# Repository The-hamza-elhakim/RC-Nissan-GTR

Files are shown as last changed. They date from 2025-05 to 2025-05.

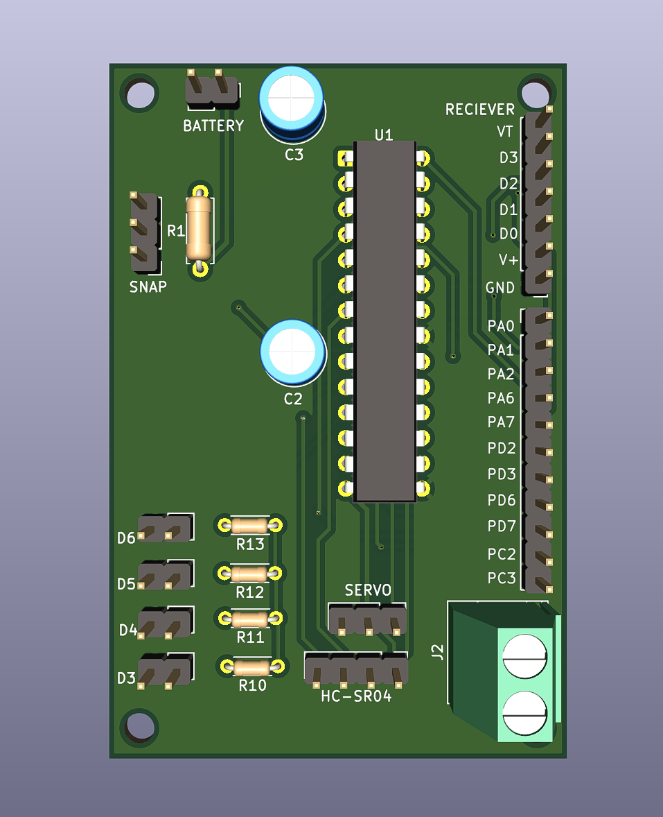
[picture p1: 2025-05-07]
Documentation/PCB schematics (KICAD)/Main PCB.png

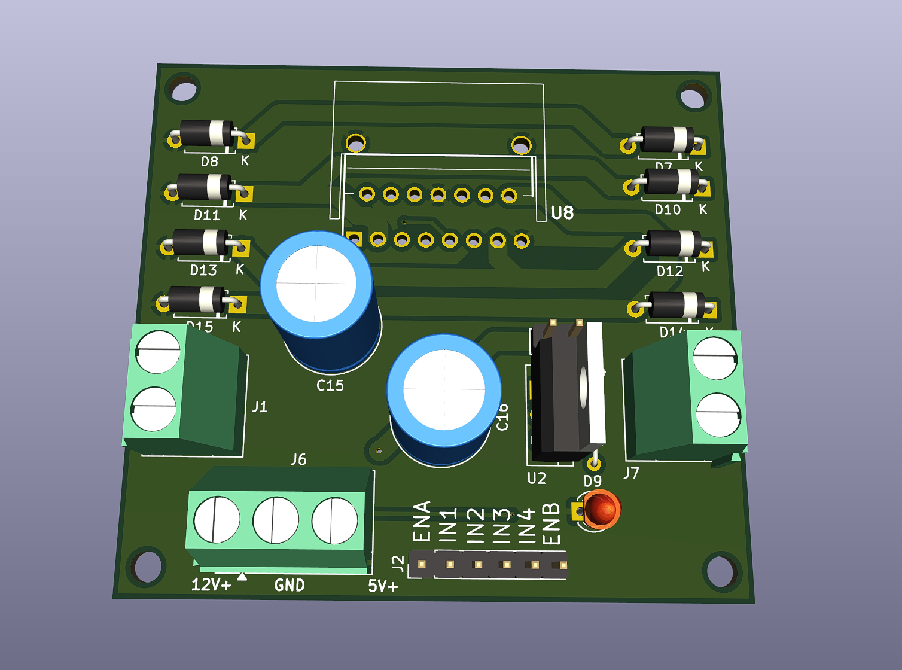
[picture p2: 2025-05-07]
Documentation/PCB schematics (KICAD)/L298N PCB.png

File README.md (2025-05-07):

# ENEL 300 RC Car – Embedded Systems Final Project

# RC-Nissan-GTR
RC Car modeled after the Iconic Nissan GTR r35. Designed from scratch using AVR128DB28 MCU, ultrasonic sensors, joystick control, I2C LCD, and L298N motor driver. Built in MPLAB X, with custom PCBs, bare-metal C firmware, and real-time sensor feedback.

## Overview
This project is a fully functional RC car built from scratch using embedded C on the AVR128DB28 microcontroller. It includes:

- motor control via custom built L298N motor driver PCB
- Ultrasonic sensor for obstacle detection
- 4 digit display for distance feedback
- Remote controller using joystick module (KY-023) and Wireless 433Mhz RF Transmitter/Receiver Modules
- Custom PCBs and real-time sensor integration

## Features
- Real-time distance sensing (HC-SR04)
- Metal detection with buzzer output
- Headlight control (GPIO driven)
- Directional motor control with PWM
- I2C LCD for debug/status

## Technologies
- AVR128DB28 microcontroller
- Bare-metal C (no Arduino)
- MPLAB X IDE
- I2C, PWM, ADC, GPIO
- Custom PCB Design (KiCAD)

## Documentation
See [`Documentation/`](Documentation/) folder for project reports and architecture

Read the full project report here:  
[ENEL 300 RC Car Final Report (Google Docs)](https://docs.google.com/document/d/1p-epSyup4PSlBaB8h3Y5LkGUN4icb1V6V-HfzxVr1pI/edit?tab=t.0)

## Author
Hamza Elhakim – Electrical and Computer Engineering Student

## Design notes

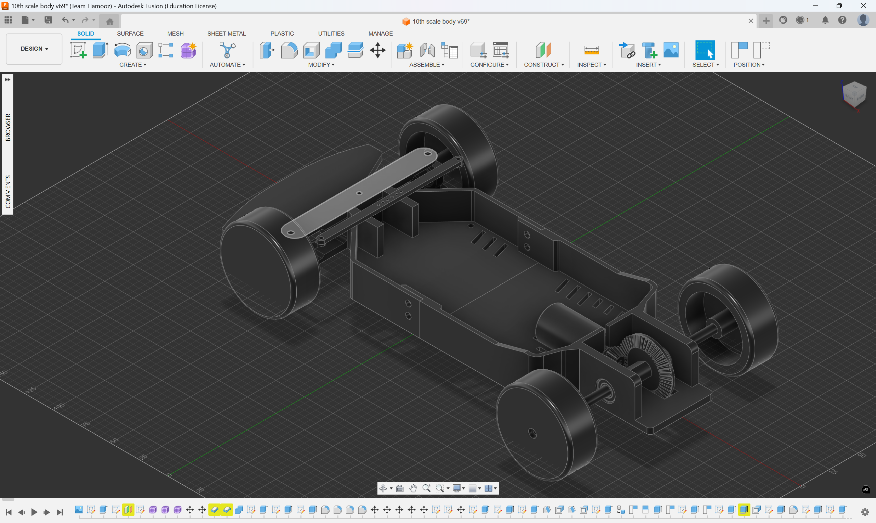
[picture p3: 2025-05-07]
Documentation/3D print designs (Fusion 360)/chassis.png

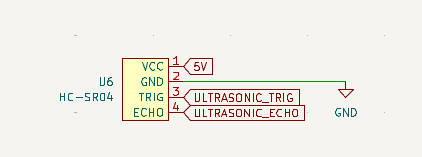
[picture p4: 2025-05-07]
Documentation/PCB schematics (KICAD)/Ultrasonic sensor.png

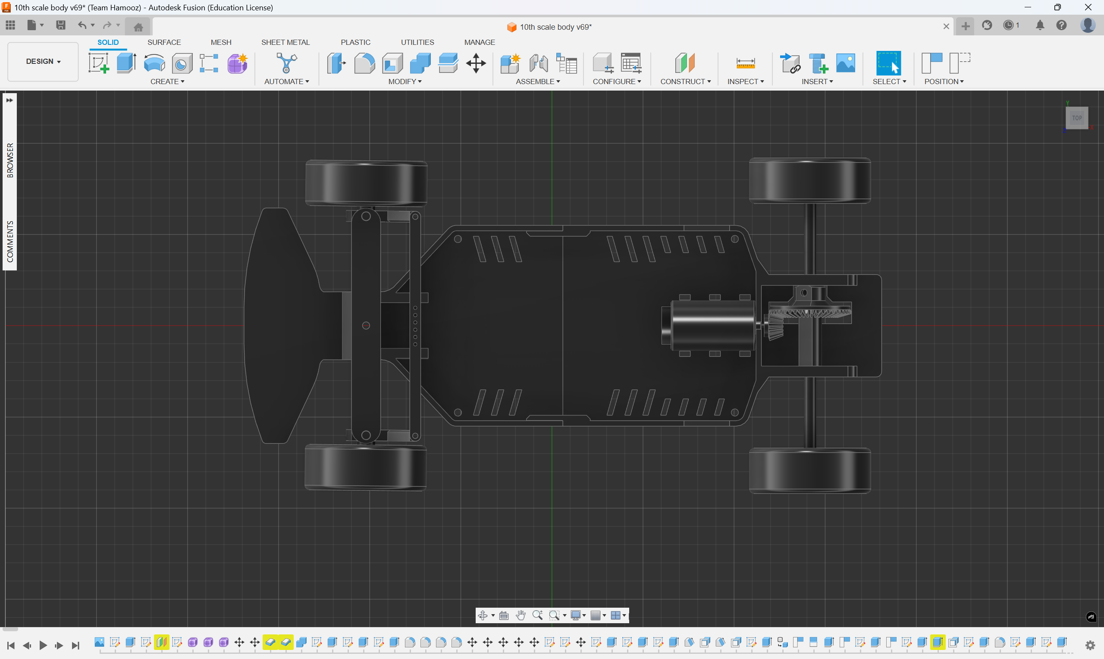
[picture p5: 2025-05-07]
Documentation/3D print designs (Fusion 360)/top view (chassis).png

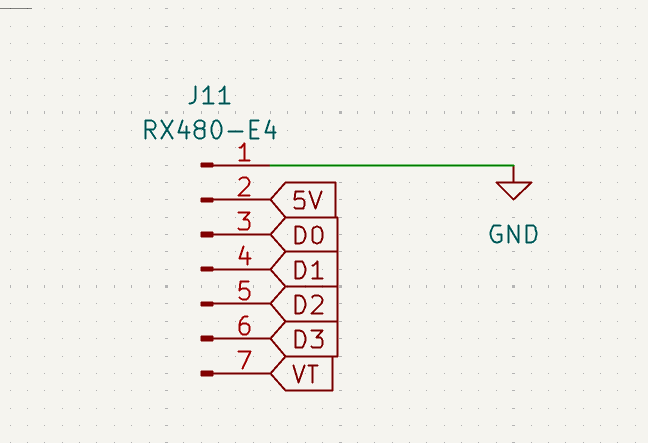
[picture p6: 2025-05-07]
Documentation/PCB schematics (KICAD)/Reciever.png

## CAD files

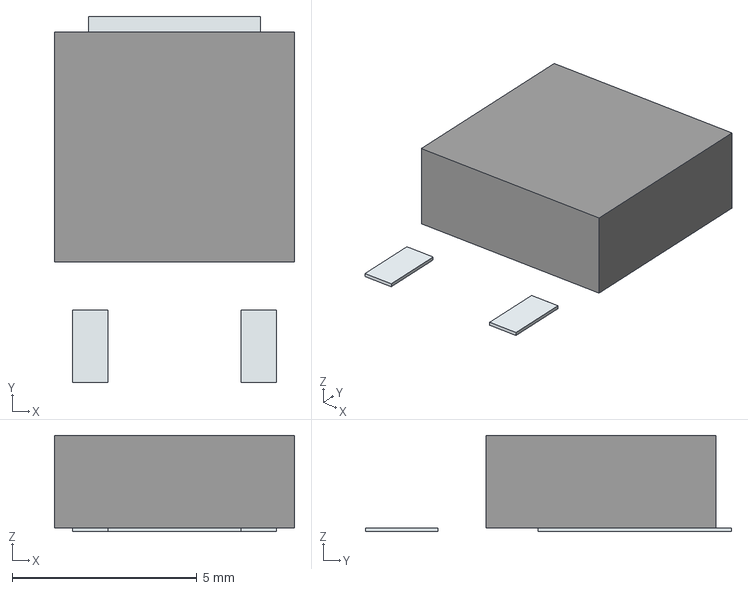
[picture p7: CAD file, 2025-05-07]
Hardware/Main/LIB_IPD90P03P4L04ATMA2/IPD90P03P4L04ATMA2/3D/IPD90P03P4L04ATMA2.stp
6.50 x 9.90 x 2.60 mm
Pins

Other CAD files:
Hardware/Main/LIB_IPD90P03P4L04ATMA2/IPD90P03P4L04ATMA2/Allegro/ipd90p03p4l04atma2.psm
Hardware/Main/LIB_IPD90P03P4L04ATMA2/IPD90P03P4L04ATMA2/DEHDL/ipd90p03p4l04atma2/chips/chips.prt

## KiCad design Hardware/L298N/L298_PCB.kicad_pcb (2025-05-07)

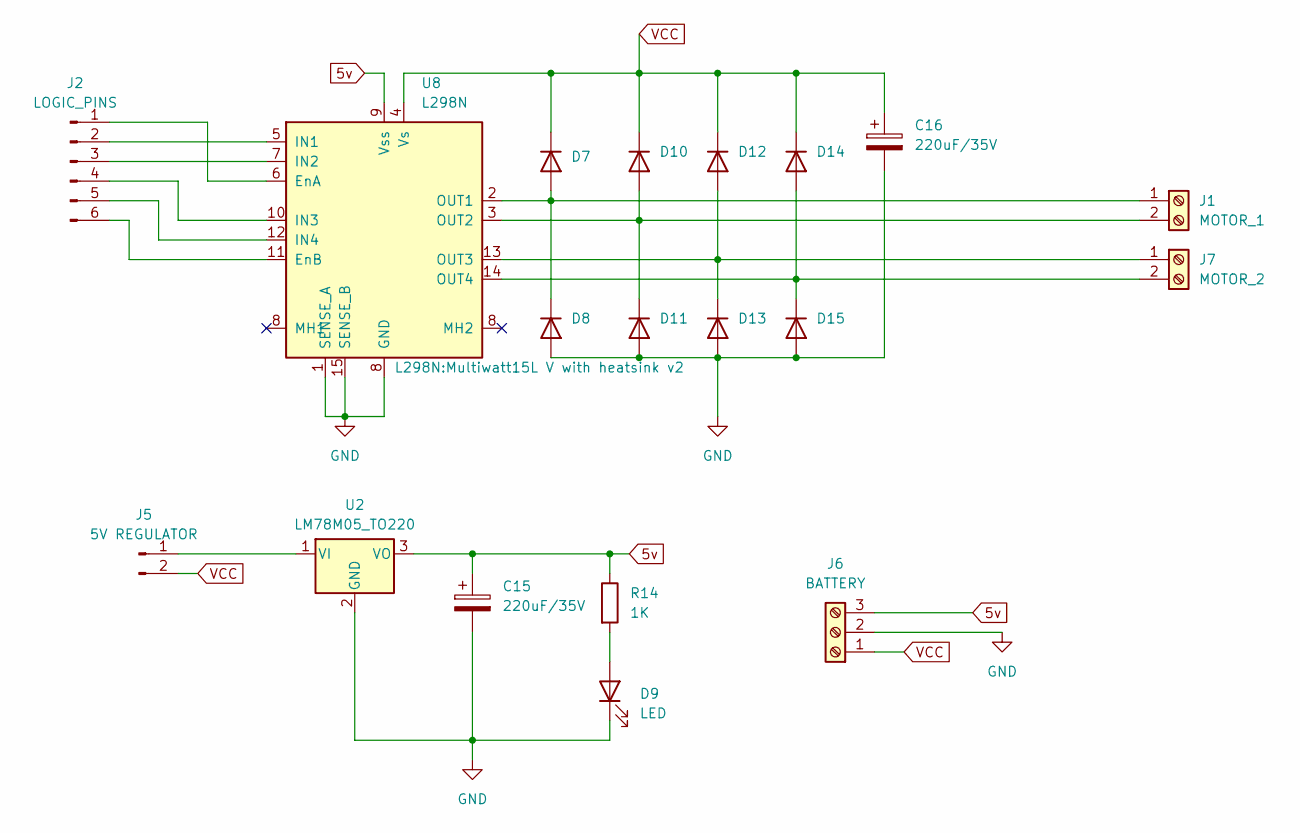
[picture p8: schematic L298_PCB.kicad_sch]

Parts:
C15, C16: 220uF/35V; C_Radial_D10.0mm_H16.0mm_P5.00mm
D7: D_A-405_P7.62mm_Horizontal
D8, D10, D11, D12, D13, D14, D15: .; D_A-405_P7.62mm_Horizontal
D9: LED; LED_D3.0mm
J1: MOTOR_1; TerminalBlock_Phoenix_MKDS-1,5-2-5.08_1x02_P5.08mm_Horizont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
J2: LOGIC_PINS; PinHeader_1x06_P2.54mm_Vertical
J5: 5V REGULATOR; PinHeader_1x02_P2.54mm_Vertical
J6: BATTERY; TerminalBlock_Phoenix_MKDS-1,5-3_1x03_P5.00mm_Horizontal
J7: MOTOR_2; TerminalBlock_Phoenix_MKDS-1,5-2-5.08_1x02_P5.08mm_Horizont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
R14: 1K; R_Axial_DIN0204_L3.6mm_D1.6mm_P7.62mm_Horizontal
U2: LM78M05_TO220; TO-220-3_Vertical
U8: L298N; Multiwatt15L V with heatsink v2

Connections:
5v: C15.1, J6.3, R14.1, U2.3 (VO), U8.9 (Vss)
GND: C15.2, C16.2, D8.2 (A), D9.1 (K), D11.2 (A), D13.2 (A), D15.2 (A), J6.2, U2.2 (GND), U8.1 (SENSE_A), U8.8 (GND), U8.15 (SENSE_B)
unnamed: D7.2 (A), D8.1 (K), J1.1, U8.2 (OUT1)
unnamed: D9.2 (A), R14.2
unnamed: D10.2 (A), D11.1 (K), J1.2, U8.3 (OUT2)
unnamed: D12.2 (A), D13.1 (K), J7.1, U8.13 (OUT3)
unnamed: D14.2 (A), D15.1 (K), J7.2, U8.14 (OUT4)
unnamed: J2.1, U8.6 (EnA)
unnamed: J2.2, U8.5 (IN1)
unnamed: J2.3, U8.7 (IN2)
unnamed: J2.4, U8.10 (IN3)
unnamed: J2.5, U8.12 (IN4)
unnamed: J2.6, U8.11 (EnB)
unnamed: J5.1, U2.1 (VI)
VCC: C16.1, D7.1 (K), D10.1 (K), D12.1 (K), D14.1 (K), J5.2, J6.1, U8.4 (Vs)

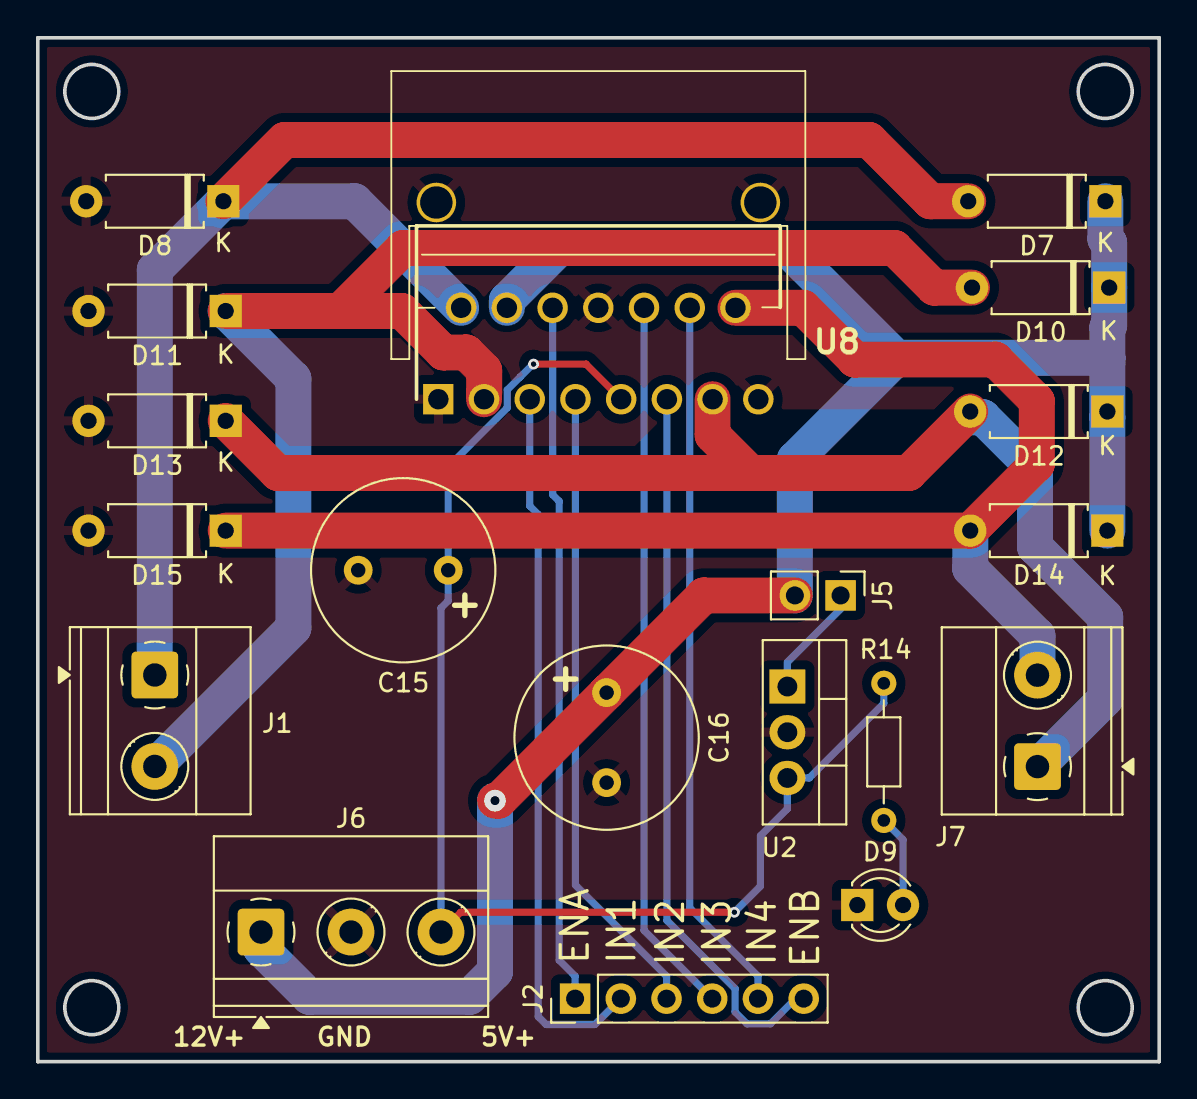
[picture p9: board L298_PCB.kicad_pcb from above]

Board: 2 copper layers, 62.3 x 56.9 mm, 19 parts (0 on the bottom side), 15 nets.

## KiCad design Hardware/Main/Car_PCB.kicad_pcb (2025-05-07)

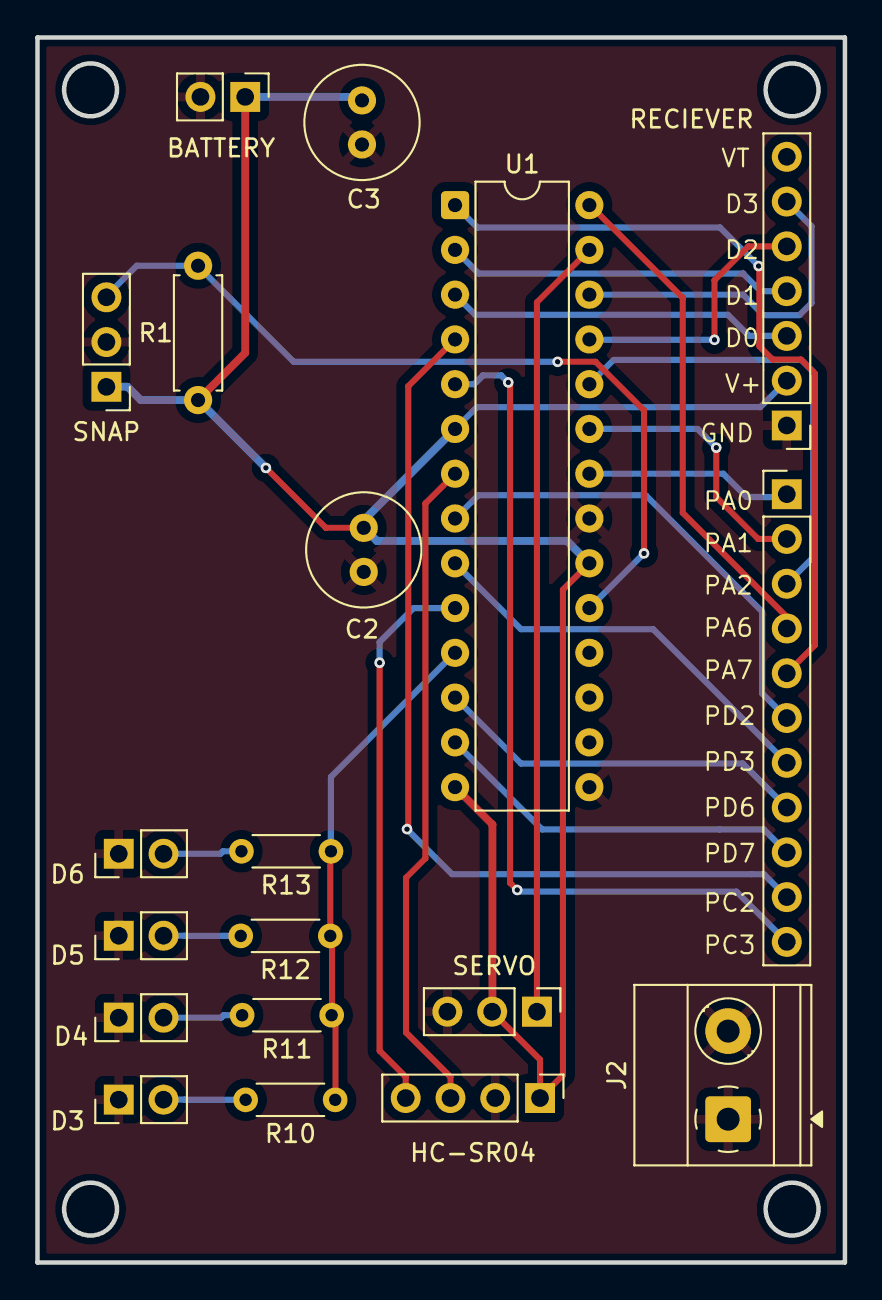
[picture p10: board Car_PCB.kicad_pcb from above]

Board: 2 copper layers, 45.8 x 69.5 mm, 19 parts (0 on the bottom side), 26 nets.

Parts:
BATTERY: BATTERY; PinHeader_1x02_P2.54mm_Vertical
C2, C3: 1uF; C_Radial_D6.3mm_H5.0mm_P2.50mm
D3, D4, D5, D6: LED; PinHeader_1x02_P2.54mm_Vertical
HC-SR04: HC-SR04; PinHeader_1x04_P2.54mm_Vertical
J2: COMMON GND; TerminalBlock_Phoenix_MKDS-1,5-2_1x02_P5.00mm_Horizontal
J3: SPARE_PINS; PinHeader_1x11_P2.54mm_Vertical
R1: 1.2K; R_Axial_DIN0207_L6.3mm_D2.5mm_P7.62mm_Horizontal
R10, R11, R12, R13: 120; R_Axial_DIN0204_L3.6mm_D1.6mm_P5.08mm_Horizontal
RECIEVER: RX480-E4; PinHeader_1x07_P2.54mm_Vertical
SERVO: Motor_Servo; PinHeader_1x03_P2.54mm_Vertical
SNAP: SNAP PROGRAMER; PinHeader_1x03_P2.54mm_Vertical
U1: AVR128DB28x-xSP; DIP-28_W7.62mm

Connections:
5V: BATTERY.1, C2.1, C3.1, HC-SR04.1 (VCC), R1.1, RECIEVER.2, SERVO.2 (+), SNAP.1, U1.6 (VDDIO2), U1.14 (AVDD), U1.20 (VDD)
D0: RECIEVER.3, U1.3 (PC1)
D1: RECIEVER.4, U1.2 (PC0)
D2: RECIEVER.5, U1.25 (PA3)
D3: RECIEVER.6, U1.26 (PA4)
GND: BATTERY.2, C2.2, C3.2, D3.1 (K), D4.1 (K), D5.1 (K), D6.1 (K), HC-SR04.2 (GND), J2.1, J2.2, RECIEVER.1, SERVO.3 (-), SNAP.2, U1.15 (AGND), U1.21 (GND)
LED_SIG: R10.1, R11.1, R12.1, R13.1, U1.11 (PD5)
unnamed: D3.2 (A), R10.2
unnamed: D4.2 (A), R11.2
unnamed: D5.2 (A), R12.2
unnamed: D6.2 (A), R13.2
unnamed: R1.2, SNAP.3, U1.19 (UPDI)
PA0: J3.1, U1.22 (XTALHF1/PA0)
PA1: J3.2, U1.23 (XTALHF2/PA1)
PA2: J3.3, U1.24 (PA2)
PA6: J3.4, U1.28 (PA6)
PA7: J3.5, U1.1 (PA7)
PC2: J3.10, U1.4 (PC2)
PC3: J3.11, U1.5 (PC3)
PD2: J3.6, U1.8 (PD2)
PD3: J3.7, U1.9 (PD3)
PD6: J3.8, U1.12 (PD6)
PD7: J3.9, U1.13 (VREFA/PD7)
SERVO_SIG: SERVO.1 (PWM), U1.27 (PA5)
ULTRASONIC_ECHO: HC-SR04.4 (ECHO), U1.10 (PD4)
ULTRASONIC_TRIG: HC-SR04.3 (TRIG), U1.7 (PD1)

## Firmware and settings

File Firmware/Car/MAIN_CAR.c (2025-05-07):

#define F_CPU 4000000UL
#include <avr/io.h>
#include <avr/interrupt.h>
#include <util/delay.h>
#include <stdint.h>
#include <stdbool.h>

// === Pin Definitions ===
#define TM1637_CLK_PIN 7 // PD7
#define TM1637_DIO_PIN 6 // PD6
#define TM1637_PORT PORTD

#define HC_SR04_TRIG_PIN 1 // PD1
#define HC_SR04_ECHO_PIN 4 // PD4

#define MOTOR_ENA_PIN 0  // PA0 (PWM)
#define MOTOR_IN1_PIN 1  // PA1
#define MOTOR_IN2_PIN 2  // PA2
#define MOTOR_PORT PORTA

#define RF_FORWARD_MOTOR_PIN 0   // PC0
#define RF_BACKWARDS_MOTOR_PIN 1 // PC1
#define RF_PORT PORTC

#define SERVO_RIGHT_PIN 3 // PA3
#define SERVO_LEFT_PIN 4 // PA4
#define SERVO_PWM_PIN 5 // PA5
#define SERVO_PORT PORTA


#define TM1637_BRIGHTNESS 0x0F
#define TM1637_CMD_SET_DATA 0x40
#define TM1637_CMD_SET_ADDR 0xC0
#define TM1637_CMD_DISPLAY_CTRL 0x88

#define METAL_INPUT_PIN   PIN6_bm   // PA6 input from metal detector
#define BUZZER_OUTPUT_PIN PIN2_bm   // PD2 output to buzzer
#define THRESHOLD_DIFF      1

#define SERVO_PWM_PIN 5      // PA5

// For 4MHz system clock
#define TIMER_PRESCALER      2       // Clock divider
#define TIMER_FREQ           (F_CPU / TIMER_PRESCALER)  // 2 MHz
#define MS_TO_TICKS(ms)      ((uint16_t)((ms) * (TIMER_FREQ / 1000)))  // Convert ms to ticks

// Servo pulse parameters (in timer ticks)
#define SERVO_PERIOD         MS_TO_TICKS(20)    // 20ms period (50Hz)
#define SERVO_MIN_PULSE      MS_TO_TICKS(0.85)     // 1ms pulse (0 degrees)
#define SERVO_MID_PULSE      MS_TO_TICKS(1.53)   // 1.5ms pulse (90 degrees)
#define SERVO_MAX_PULSE      MS_TO_TICKS(2.35)     // 2ms pulse (180 degrees)

#define FILTER_SIZE 5

#define COUNT_WINDOW_TICKS 62500UL

// ===== DEFINITIONS ===== //

#ifndef TCB_ENABLE_bm
#define TCB_ENABLE_bm     (1 << 0)
#endif

#ifndef TCB_CLKSEL_CLKDIV64_gc
#define TCB_CLKSEL_CLKDIV64_gc  (0x03 << 1)
#endif

#ifndef TCB_INT_OVF_bm
#define TCB_INT_OVF_bm    (1 << 0)
#endif

typedef enum {
    SERVO_PULSE_HIGH,
    SERVO_PULSE_LOW
} servo_state_t;

typedef enum {
    MOTOR_FORWARD,
    MOTOR_REVERSE
} motor_dir_t;

volatile uint16_t edge_count = 0;
volatile uint16_t baseline_count = 0;
volatile uint8_t  counting_enabled = 1;
volatile uint8_t  baseline_set = 0;
volatile uint8_t  startup_counter = 0;
volatile uint16_t echo_end = 0;
volatile uint8_t echo_done = 0;
uint16_t distance_buffer[FILTER_SIZE] = {0};
uint8_t buffer_index = 0;
uint8_t buffer_filled = 0;

volatile bool motor_override = false;
volatile bool motor_direction = true;

volatile servo_state_t servo_state = SERVO_PULSE_HIGH;
volatile uint16_t servo_pulse_width = SERVO_MID_PULSE;

const uint8_t digitToSegment[10] = {
  0x3F, 0x06, 0x5B, 0x4F,
  0x66, 0x6D, 0x7D, 0x07,
  0x7F, 0x6F
};

// ===== Display Functions ===== //

void tm1637_start(void);
void tm1637_stop(void);
void tm1637_write_byte(uint8_t b);
void tm1637_display(uint8_t segments[]);
void display_distance(uint16_t value);

void tm1637_init(void) {
  _delay_ms(50);
  tm1637_start();
  tm1637_write_byte(TM1637_CMD_SET_DATA);
  tm1637_stop();
  tm1637_start();
  tm1637_write_byte(TM1637_CMD_DISPLAY_CTRL | (TM1637_BRIGHTNESS & 0x07));
  tm1637_stop();
}

void display_distance(uint16_t value) {
  uint8_t digits[4] = {
    (value / 1000) % 10,
    (value / 100) % 10,
    (value / 10) % 10,
    value % 10
  };

  uint8_t segments[4];
  for (uint8_t i = 0; i < 4; i++) {
    segments[i] = digitToSegment[digits[i]];
  }

  if (value < 1000) segments[0] = 0;
  if (value < 100) segments[1] = 0;
  if (value < 10)  segments[2] = 0;

  tm1637_display(segments);
}

void tm1637_display(uint8_t segments[]) {
  tm1637_start();
  tm1637_write_byte(TM1637_CMD_SET_ADDR);
  for (uint8_t i = 0; i < 4; i++) {
    tm1637_write_byte(segments[i]);
  }
  tm1637_stop();
}

void tm1637_start(void) {
  TM1637_PORT.OUTSET = (1 << TM1637_DIO_PIN);
  TM1637_PORT.OUTSET = (1 << TM1637_CLK_PIN);
  _delay_us(2);
  TM1637_PORT.OUTCLR = (1 << TM1637_DIO_PIN);
  _delay_us(2);
  TM1637_PORT.OUTCLR = (1 << TM1637_CLK_PIN);
  _delay_us(2);
}

void tm1637_stop(void) {
  TM1637_PORT.OUTCLR = (1 << TM1637_CLK_PIN);
  _delay_us(2);
  TM1637_PORT.OUTCLR = (1 << TM1637_DIO_PIN);
  _delay_us(2);
  TM1637_PORT.OUTSET = (1 << TM1637_CLK_PIN);
  _delay_us(2);
  TM1637_PORT.OUTSET = (1 << TM1637_DIO_PIN);
  _delay_us(2);
}

void tm1637_write_byte(uint8_t b) {
  for (uint8_t i = 0; i < 8; i++) {
    TM1637_PORT.OUTCLR = (1 << TM1637_CLK_PIN);
    _delay_us(2);
    if (b & 0x01)
      TM1637_PORT.OUTSET = (1 << TM1637_DIO_PIN);
    else
      TM1637_PORT.OUTCLR = (1 << TM1637_DIO_PIN);
    _delay_us(2);
    TM1637_PORT.OUTSET = (1 << TM1637_CLK_PIN);
    _delay_us(2);
    b >>= 1;
  }

  TM1637_PORT.OUTCLR = (1 << TM1637_CLK_PIN);
  TM1637_PORT.DIRCLR = (1 << TM1637_DIO_PIN);
  _delay_us(5);
  TM1637_PORT.OUTSET = (1 << TM1637_CLK_PIN);
  _delay_us(2);
  TM1637_PORT.OUTCLR = (1 << TM1637_CLK_PIN);
  TM1637_PORT.DIRSET = (1 << TM1637_DIO_PIN);
  _delay_us(2);
}

// ===== Motor & Input Handling ===== //

void init_pwm(void) {
  PORTMUX.TCAROUTEA = PORTMUX_TCA0_PORTA_gc;
  TCA0.SINGLE.CTRLA = TCA_SINGLE_CLKSEL_DIV64_gc | TCA_SINGLE_ENABLE_bm;
  TCA0.SINGLE.CTRLB = TCA_SINGLE_WGMODE_SINGLESLOPE_gc | TCA_SINGLE_CMP0EN_bm;
  TCA0.SINGLE.PER = 255;
  TCA0.SINGLE.CMP0 = 0;
}

void rf_input_init(void) {
  // Set PA3, PA4 as inputs
  PORTC.DIRCLR = (1 << RF_FORWARD_MOTOR_PIN) | (1 << RF_BACKWARDS_MOTOR_PIN);

  // Enable internal pull-ups
  PORTC.PIN3CTRL = PORT_PULLUPEN_bm;
  PORTC.PIN4CTRL = PORT_PULLUPEN_bm;
  PORTC.PIN5CTRL = PORT_PULLUPEN_bm;
  PORTC.PIN6CTRL = PORT_PULLUPEN_bm;
  
  // Set PA5, PA6 as inputs
  PORTA.DIRCLR = (1 << SERVO_RIGHT_PIN) | (1 << SERVO_LEFT_PIN);
  
  // Enable internal pull-ups
  PORTA.PIN3CTRL = PORT_PULLUPEN_bm;
  PORTA.PIN4CTRL = PORT_PULLUPEN_bm;
}

motor_dir_t last_motor_dir = MOTOR_FORWARD;

void controlMotor(void) {
  
  if (motor_override) return;  
  
  if (PORTC.IN & (1 << RF_FORWARD_MOTOR_PIN)) {
    MOTOR_PORT.OUTCLR = (1 << MOTOR_IN1_PIN);
    MOTOR_PORT.OUTSET = (1 << MOTOR_IN2_PIN);
    TCA0.SINGLE.CMP0 = 255;
    last_motor_dir = MOTOR_FORWARD;
    
  } else if (PORTC.IN & (1 << RF_BACKWARDS_MOTOR_PIN)) {
    MOTOR_PORT.OUTSET = (1 << MOTOR_IN1_PIN);
    MOTOR_PORT.OUTCLR = (1 << MOTOR_IN2_PIN);
    TCA0.SINGLE.CMP0 = 255;
    last_motor_dir = MOTOR_REVERSE;
    
  } else {
    MOTOR_PORT.OUTCLR = (1 << MOTOR_IN1_PIN) | (1 << MOTOR_IN2_PIN);
    TCA0.SINGLE.CMP0 = 0;
  }
}

void drive_motor_in_last_direction(void) {
    if (last_motor_dir == MOTOR_FORWARD) {
        MOTOR_PORT.OUTCLR = (1 << MOTOR_IN1_PIN);
        MOTOR_PORT.OUTSET = (1 << MOTOR_IN2_PIN);
        TCA0.SINGLE.CMP0 = 255;
    } else if (last_motor_dir == MOTOR_REVERSE) {
        MOTOR_PORT.OUTSET = (1 << MOTOR_IN1_PIN);
        MOTOR_PORT.OUTCLR = (1 << MOTOR_IN2_PIN);
        TCA0.SINGLE.CMP0 = 255;
    } else {
        // Stay off if direction is unknown
        TCA0.SINGLE.CMP0 = 0;
    }
}

// ===== METAL DETECTOR ===== //

void PORT_init(void) {
    // PA6: input from 555 timer
    PORTA.DIRCLR = METAL_INPUT_PIN;
    PORTA.PIN6CTRL = PORT_ISC_RISING_gc;  // Trigger ISR on rising edge

    // Optional: pull-down resistor for stability
    // PORTA.PIN6CTRL |= PORT_PULLUPEN_bm;

    // PD2: output to buzzer
    PORTD.DIRSET = BUZZER_OUTPUT_PIN;
    PORTD.OUTCLR = BUZZER_OUTPUT_PIN;
}

void TCB2_init(void) {
    TCB2.CNT = 0;
    TCB2.CCMP = COUNT_WINDOW_TICKS;
    TCB2.CTRLA = TCB_CLKSEL_CLKDIV64_gc | TCB_ENABLE_bm;
    TCB2.CTRLB = 0;
    TCB2.INTCTRL = TCB_INT_OVF_bm;
}



ISR(PORTA_PORT_vect) {
    if ((PORTA.INTFLAGS & METAL_INPUT_PIN) && counting_enabled) {
        PORTA.INTFLAGS = METAL_INPUT_PIN;
        edge_count++;
    }
}


ISR(TCB2_INT_vect) {
    TCB2.INTFLAGS = TCB_INT_OVF_bm;
    counting_enabled = 0;

    if (!baseline_set) {
        startup_counter++;
        if (startup_counter >= 5) {
            baseline_count = edge_count;
            baseline_set = 1;
        }
        edge_count = 0;
        counting_enabled = 1;
        return;
    }

    if (edge_count >= baseline_count + THRESHOLD_DIFF) {
        PORTD.OUTSET = BUZZER_OUTPUT_PIN;
    } else if (edge_count <= baseline_count) {
        PORTD.OUTCLR = BUZZER_OUTPUT_PIN;
    }

    edge_count = 0;
    counting_enabled = 1;
}


// === Servo Input & Handling === //

// === Initialize Servo ===
void init_servo(void) {
    // Set up output pin
    PORTA.DIRSET = (1 << SERVO_PWM_PIN);
    PORTA.OUTCLR = (1 << SERVO_PWM_PIN);
    
    // Configure TCB1 for compare interrupt mode
    TCB1.CTRLA = TCB_CLKSEL_DIV2_gc;       // Use prescaled clock (2MHz)
    
    // Since we don't have a DIV64 option directly, we'll adjust our calculations
    #undef TIMER_PRESCALER
    #define TIMER_PRESCALER 2       // Actual prescaler value
    TCB1.CTRLB = TCB_CNTMODE_INT_gc;       // Periodic interrupt mode
    TCB1.CCMP = servo_pulse_width;         // Start with mid pulse
    TCB1.INTCTRL = TCB_CAPT_bm;            // Enable capture interrupt
    
    // Clear interrupt flag and enable timer
    TCB1.INTFLAGS = TCB_CAPT_bm;
    TCB1.CTRLA |= TCB_ENABLE_bm;
}

// Set servo position (0-180 degrees)
void set_servo_position(uint8_t degrees) {
    // Constrain input to 0-180 degrees
    if (degrees > 180) degrees = 180;
    
    // Map degrees to pulse width
    if (degrees == 0) {
        servo_pulse_width = SERVO_MIN_PULSE;
    } else if (degrees == 90) {
        servo_pulse_width = SERVO_MID_PULSE;
    } else if (degrees == 180) {
        servo_pulse_width = SERVO_MAX_PULSE;
    } else if (degrees < 90) {
        // Interpolate between 0 and 90 degrees
        servo_pulse_width = SERVO_MIN_PULSE + 
            ((uint32_t)(degrees) * (SERVO_MID_PULSE - SERVO_MIN_PULSE)) / 90;
    } else {
        // Interpolate between 90 and 180 degrees
        servo_pulse_width = SERVO_MID_PULSE + 
            ((uint32_t)(degrees - 90) * (SERVO_MAX_PULSE - SERVO_MID_PULSE)) / 90;
    }
}

// Update servo from input pins
void update_servo_from_pins(void) {
    if (PORTA.IN & (1 << SERVO_RIGHT_PIN)) {
        set_servo_position(0);     // Right position
        drive_motor_in_last_direction();
        motor_override = true;
        
    } else if (PORTA.IN & (1 << SERVO_LEFT_PIN)) {
        set_servo_position(180);   // Left position
        drive_motor_in_last_direction();
        motor_override = true;
        
    } else {
        set_servo_position(90);    // Center position
        motor_override = false;
    }
}


// Interrupt handler for servo timing
ISR(TCB1_INT_vect) {
    // Clear interrupt flag
    TCB1.INTFLAGS = TCB_CAPT_bm;
    
    switch (servo_state) {
        case SERVO_PULSE_HIGH:
            // End of HIGH pulse
            PORTA.OUTCLR = (1 << SERVO_PWM_PIN);    // Set pin LOW
            TCB1.CCMP = SERVO_PERIOD - servo_pulse_width;  // Set time for LOW period
            servo_state = SERVO_PULSE_LOW;
            break;
            
        case SERVO_PULSE_LOW:
            // End of LOW pulse (end of cycle)
            PORTA.OUTSET = (1 << SERVO_PWM_PIN);    // Set pin HIGH
            TCB1.CCMP = servo_pulse_width;          // Set time for next HIGH period
            servo_state = SERVO_PULSE_HIGH;
            break;
    }
}


// ===== SENSOR HELPERS ===== //

ISR(TCB0_INT_vect) {
  TCB0.INTFLAGS = TCB_OVF_bm;
  echo_done = 1;
}

ISR(PORTD_PORT_vect) {
  if (PORTD.INTFLAGS & (1 << HC_SR04_ECHO_PIN)) {
    if (PORTD.IN & (1 << HC_SR04_ECHO_PIN)) {
      TCB0.CNT = 0;
      TCB0.CTRLA |= TCB_ENABLE_bm;
    } else {
      echo_end = TCB0.CNT;
      TCB0.CTRLA &= ~TCB_ENABLE_bm;
      echo_done = 1;
    }
    PORTD.INTFLAGS = (1 << HC_SR04_ECHO_PIN);
  }
}


void timer_init(void) {
  TCB0.CTRLA = TCB_CLKSEL_DIV2_gc;
  TCB0.CTRLB = TCB_CNTMODE_INT_gc;
  TCB0.CCMP = 60000;
  TCB0.INTCTRL = TCB_OVF_bm;
}

void trigger_measurement(void) {
  TCB0.CTRLA &= ~TCB_ENABLE_bm;
  TCB0.INTFLAGS = TCB_OVF_bm;
  PORTD.INTFLAGS = (1 << HC_SR04_ECHO_PIN);
  PORTD.OUTSET = (1 << HC_SR04_TRIG_PIN);
  _delay_us(10);
  PORTD.OUTCLR = (1 << HC_SR04_TRIG_PIN);
}

uint16_t calculate_distance(void) {
  if (echo_end == 0) return 0;
  return echo_end / 117;
}

uint16_t apply_moving_average(uint16_t new_distance) {
  distance_buffer[buffer_index] = new_distance;
  buffer_index = (buffer_index + 1) % FILTER_SIZE;
  if (buffer_index == 0) buffer_filled = 1;
  uint32_t sum = 0;
  uint8_t count = buffer_filled ? FILTER_SIZE : buffer_index;
  for (uint8_t i = 0; i < count; i++) sum += distance_buffer[i];
  return sum / (count ? count : 1);
}

void init_pins(void) {
  MOTOR_PORT.DIRSET = (1 << MOTOR_ENA_PIN) | (1 << MOTOR_IN1_PIN) | (1 << MOTOR_IN2_PIN);
  PORTD.DIRSET = (1 << TM1637_CLK_PIN) | (1 << TM1637_DIO_PIN) | (1 << HC_SR04_TRIG_PIN);
  PORTD.DIRCLR = (1 << HC_SR04_ECHO_PIN);
  PORTD.PIN4CTRL = PORT_PULLUPEN_bm | PORT_ISC_BOTHEDGES_gc;
  PORTD.DIRSET = (1 << 5) | (1 << 3);  // Set PD5 and PD3 as output

}

// ===== LED's ===== //

void update_motor_leds(void) {
    if (last_motor_dir == MOTOR_FORWARD) {
        PORTD.OUTSET = (1 << 5);
        PORTD.OUTCLR = (1 << 3);
    } else if (last_motor_dir == MOTOR_REVERSE) {
        PORTD.OUTSET = (1 << 3);
        PORTD.OUTCLR = (1 << 5);
    }
}


// ===== Main ===== //
int main(void) {
  CLKCTRL.MCLKCTRLA = CLKCTRL_CLKSEL_OSCHF_gc;
  CLKCTRL.MCLKCTRLB = CLKCTRL_PDIV_4X_gc | CLKCTRL_PEN_bm;

  init_pins();
  rf_input_init();
  init_pwm();
  timer_init();
  tm1637_init();
  init_servo();
  PORT_init();
  TCB2_init();

    
  sei();
  
  while (1) {
      
    // ===== MOTOR AND SERVO ===== //
    controlMotor();
    update_servo_from_pins();
    
    // ===== LED ===== //
    update_motor_leds();

    // ===== DISTANCE ===== //
    
    trigger_measurement();
    while (!echo_done);
    uint16_t distance = calculate_distance();
    distance = apply_moving_average(distance);
    echo_done = 0;
    
    if (distance > 200) distance = 200;   // cap at 200cm

    display_distance(distance);
    _delay_ms(100);
  }
}

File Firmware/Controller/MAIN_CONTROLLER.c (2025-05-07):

#define F_CPU 4000000UL
#include <avr/io.h>
#include <util/delay.h>

// === ADC Channel Assignments ===
#define MOTOR_ADC_CHANNEL 1   // PD1
#define SERVO_ADC_CHANNEL 3   // PD3

// === Output Pins (on PORTD)
#define MOTOR_FORWARD_PIN   7
#define MOTOR_BACKWARD_PIN  6
#define SERVO_RIGHT_PIN     5
#define SERVO_LEFT_PIN      4
#define OUT_PORT            PORTD

// === ADC Settings ===
#define DEADZONE_LOW 100
#define DEADZONE_HIGH 150

void adc_init(void) {
    VREF.ADC0REF = VREF_REFSEL_VDD_gc;         // VDD = 5V reference
    ADC0.CTRLC = ADC_PRESC_DIV4_gc;            // ADC Clock = F_CPU / 4
    ADC0.CTRLA = ADC_ENABLE_bm | ADC_RESSEL_12BIT_gc;  // 12-bit, enabled
}

uint16_t read_adc_12bit(uint8_t channel) {
    ADC0.MUXPOS = channel;               // Select channel (1 for PD1, 3 for PD3)
    ADC0.COMMAND = ADC_STCONV_bm;       // Start conversion
    while (!(ADC0.INTFLAGS & ADC_RESRDY_bm));
    ADC0.INTFLAGS = ADC_RESRDY_bm;      // Clear flag
    return ADC0.RES;                    // 12-bit result (0?4095)
}

uint8_t read_joystick(uint8_t channel) {
    uint16_t value = read_adc_12bit(channel);
    return (uint8_t)((value * 255UL) / 4095UL);
}


void init_pins(void) {
    OUT_PORT.DIRSET = (1 << MOTOR_FORWARD_PIN) | (1 << MOTOR_BACKWARD_PIN)
                    | (1 << SERVO_RIGHT_PIN) | (1 << SERVO_LEFT_PIN);
    OUT_PORT.OUTSET = (1 << MOTOR_FORWARD_PIN) | (1 << MOTOR_BACKWARD_PIN)
                    | (1 << SERVO_RIGHT_PIN) | (1 << SERVO_LEFT_PIN);
}

int main(void) {
    adc_init();
    init_pins();
    
    _delay_ms(500);  // Wait for joystick to stabilize
    
    while (1) {
        // === Read and filter joystick values ===
        uint16_t motor_value = read_joystick(MOTOR_ADC_CHANNEL);
        uint16_t servo_value = read_joystick(SERVO_ADC_CHANNEL);
        
        // === Motor Logic ===
        if (motor_value > DEADZONE_HIGH) {
            OUT_PORT.OUTCLR = (1 << MOTOR_FORWARD_PIN);
            OUT_PORT.OUTSET = (1 << MOTOR_BACKWARD_PIN);
        } else if (motor_value < DEADZONE_LOW) {
            OUT_PORT.OUTCLR = (1 << MOTOR_BACKWARD_PIN);
            OUT_PORT.OUTSET = (1 << MOTOR_FORWARD_PIN);
        } else {
            // In deadzone - turn both pins off
            OUT_PORT.OUTSET = (1 << MOTOR_FORWARD_PIN) | (1 << MOTOR_BACKWARD_PIN);
        }
        
        // === Servo Logic ===
        if (servo_value > DEADZONE_HIGH) {
            OUT_PORT.OUTCLR = (1 << SERVO_RIGHT_PIN);
            OUT_PORT.OUTSET = (1 << SERVO_LEFT_PIN);
        } else if (servo_value < DEADZONE_LOW) {
            OUT_PORT.OUTCLR = (1 << SERVO_LEFT_PIN);
            OUT_PORT.OUTSET = (1 << SERVO_RIGHT_PIN);
        } else {
            // In deadzone - turn both pins off
            OUT_PORT.OUTSET = (1 << SERVO_RIGHT_PIN) | (1 << SERVO_LEFT_PIN);
        }
        
        _delay_ms(10);
     
    }
    
}
